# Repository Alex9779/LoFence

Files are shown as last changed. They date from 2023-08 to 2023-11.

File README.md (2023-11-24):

# LoFence V2

LoFence V2 is an updated version of the original [LoFence](https://github.com/kiu/lofence/) tackling a few shortcomings.

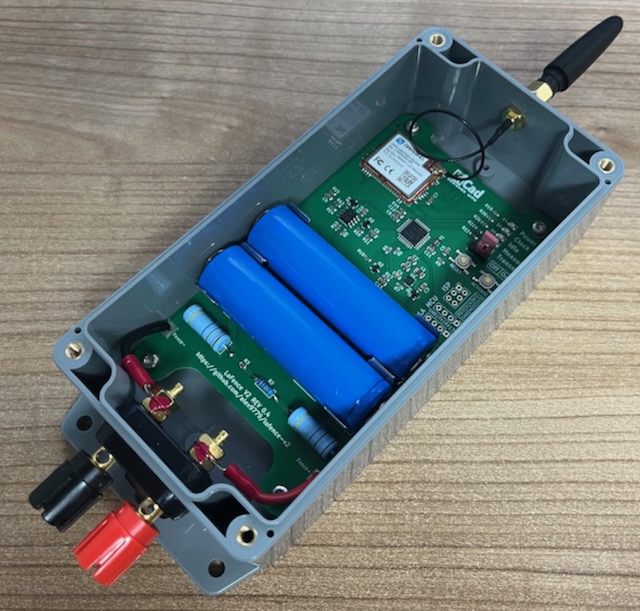
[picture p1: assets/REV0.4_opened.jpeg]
LoFence V2 opened


The main improvements are:

- case lid can be opened while main body is mounted,
- two batteries for a longer operating time,
- battery deep discharge protection using an activation circuit with a button triggered from the firmware when batteries run low,
- fully revised firmware with ability to change operating parameters by downlinks.

Other things changed are:

- Exchange RN2483 module for Dragino LA66.
  - I always had some problems with the RN2483 though serial communication protocol was easier to work with.
  - LA66 has antenna connector on board so I don't have to care about a correct antenna circuit which also has to follow the guidelines to not to violate regulatory approvals.
  - LA66 is a little cheaper.
- Implement probe resistor divider erratum.
- Optimized for assembling.
  - Changed various components to SMD variants.
  - Switch to buck-boost converter for power supply.
  - Use clamps for holding batteries instead of full holder.

For information how to build a LoFence V2 device see the [hardware repository](https://github.com/Alex9779/LoFence_Hardware).

For information how to build, upload or configure the firmware see the [firmware repository](https://github.com/Alex9779/LoFence_Firmware).

## WARNING

Do not let the debug LEDs activated during normal operation!

They need a lot of current compared to the overall device's current usage. So if activated they drastically reduce the battery runtime to just some weeks or even days.

## Device activation

The LoFence V2 is equipped with an activation circuit allowing the device to deactivate itself if the battery voltage goes under a configured level (3200mV by default for 5 cycles or 3100mV as an absolute minumum) to prevent the battery from deep discharge.

Therefore the device does not automatically activate if a battery is put in but you have to push and hold the *ACTIVATE* button for at least 1 second.

If the debug LEDs are activated the *IDLE* LED indicates that the activation process has been completed when it goes out.

After activation the device tries to join (re-join) the network, LoRaWAN counters are reset.

If joining succeeds the device will immediately do the first measurement and after that transmits the first uplink.

## Device resetting

To reset the device push the *RESET* button. After a reset the device has to be activated again.

A reset is just the same as removing all batteries and put them back in and activate the device.

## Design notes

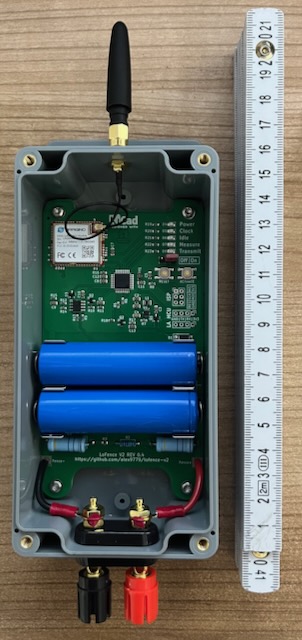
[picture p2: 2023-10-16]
assets/REV0.4_opened_with_rule.jpeg

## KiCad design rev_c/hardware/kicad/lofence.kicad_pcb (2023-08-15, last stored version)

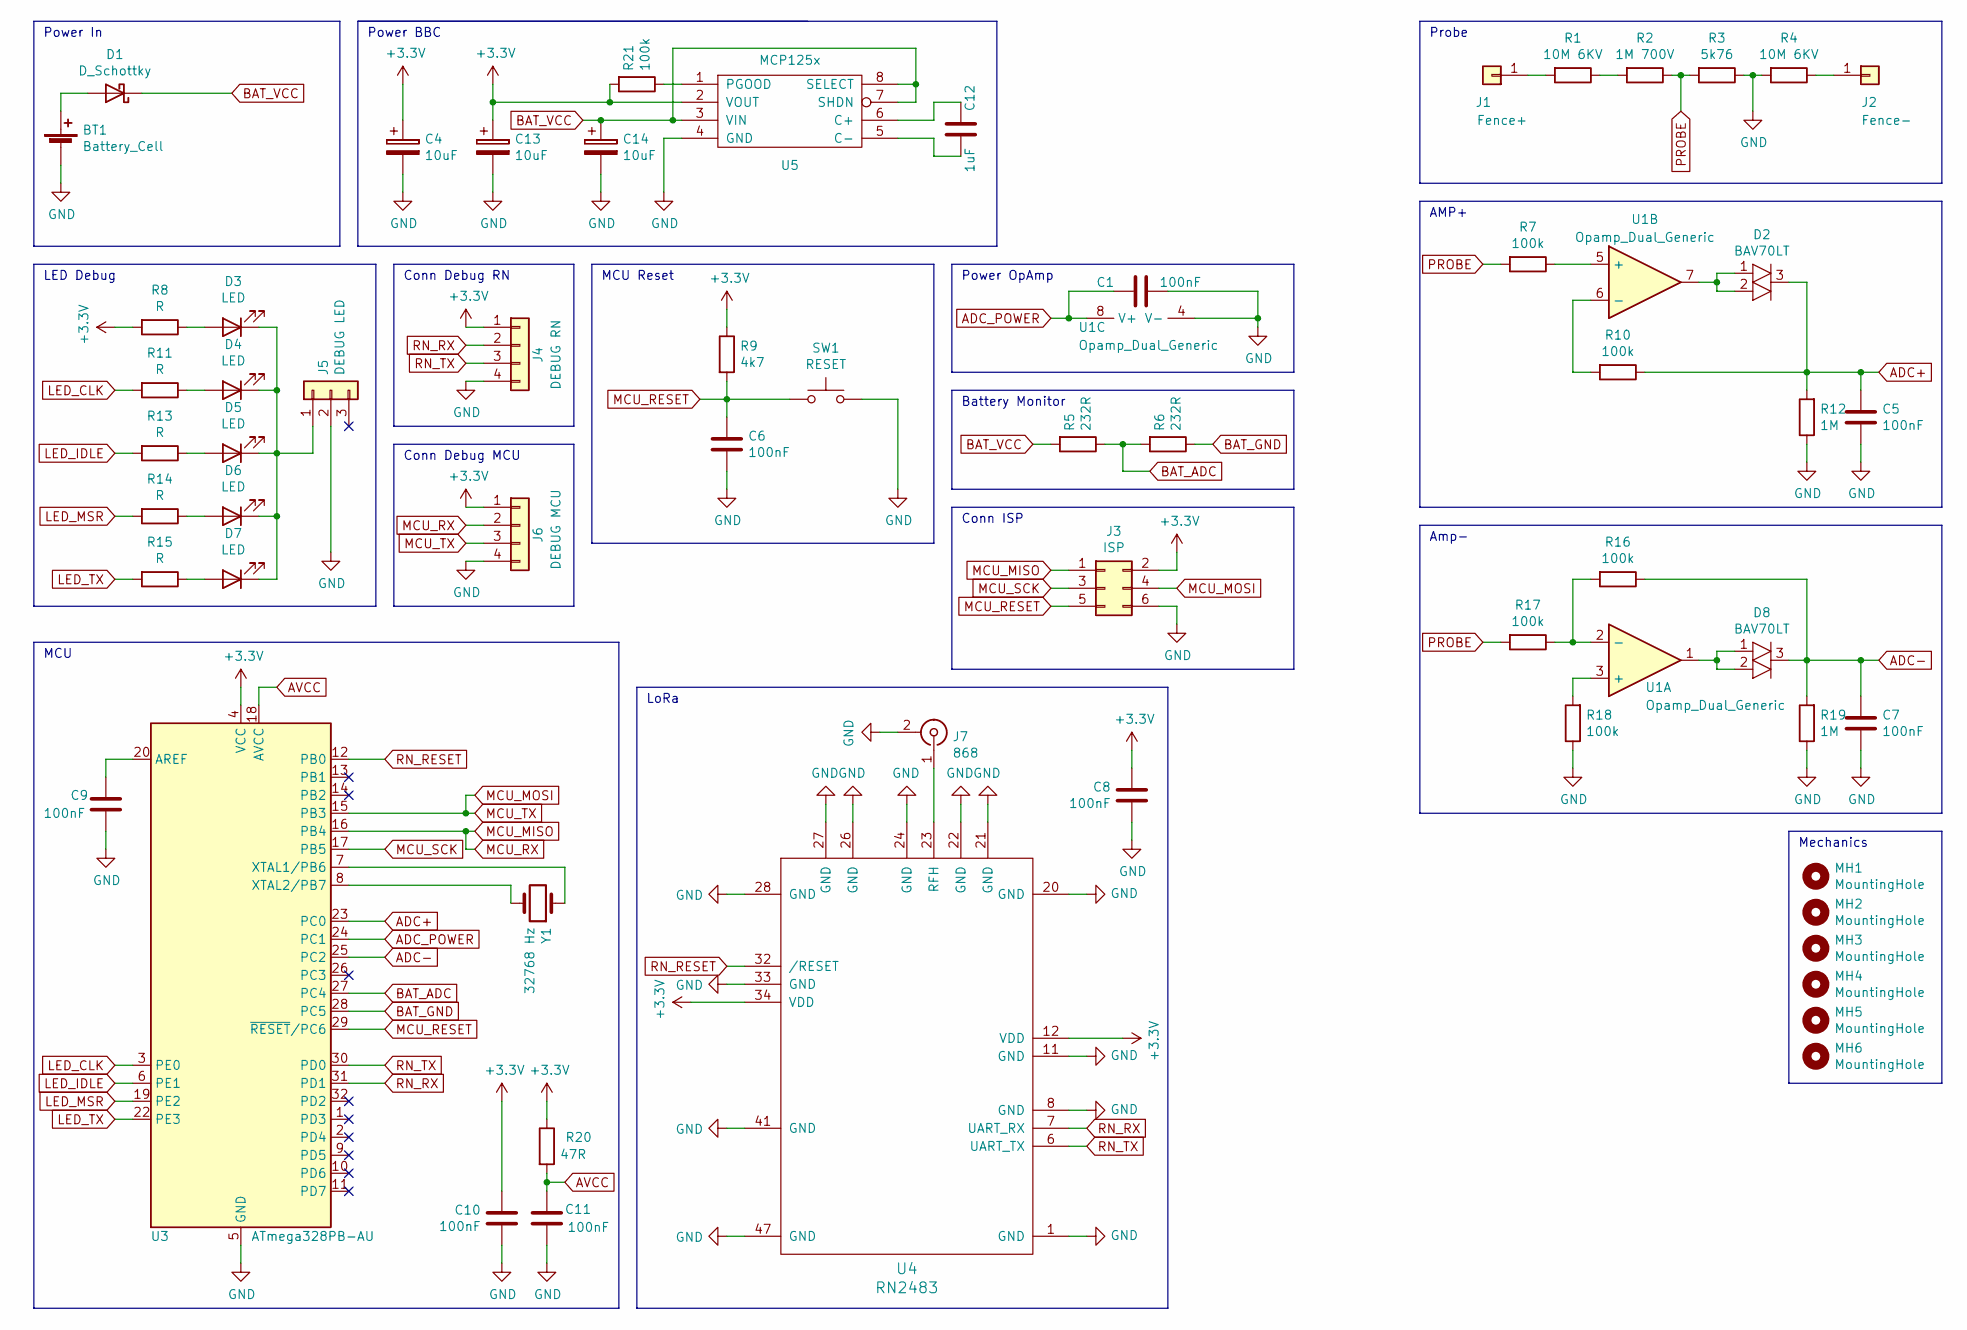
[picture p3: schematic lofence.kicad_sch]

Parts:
BT1: Battery_Cell; 18650HolderTHT
C1, C5, C6, C7, C8, C9, C10, C11: 100nF; C_0805_2012Metric_Pad1.18x1.45mm_HandSolder
C4: 10uF; CP_Elec_4x5.7
C12: 1uF; C_0805_2012Metric_Pad1.18x1.45mm_HandSolder
C13, C14: 10uF; C_1206_3216Metric_Pad1.33x1.80mm_HandSolder
D1: D_Schottky; D_SMA_Handsoldering
D2, D8: BAV70LT; SOT-23
D3, D4, D5, D6, D7: LED; LED_0805_2012Metric_Pad1.15x1.40mm_HandSolder
J1: Fence+; TestPoint_THTPad_4.0x4.0mm_Drill2.0mm
J2: Fence-; TestPoint_THTPad_4.0x4.0mm_Drill2.0mm
J3: ISP; PinHeader_2x03_P2.54mm_Vertical
J4: DEBUG RN; PinHeader_1x04_P2.54mm_Vertical
J5: DEBUG LED; PinHeader_1x03_P2.54mm_Vertical
J6: DEBUG MCU; PinHeader_1x04_P2.54mm_Vertical
J7: 868; U.FL
MH1, MH2, MH3, MH4, MH5, MH6: MountingHole; MountingHole_2.7mm_M2.5
R1, R4: 10M 6KV; R_Axial_DIN0516_L15.5mm_D5.0mm_P20.32mm_Horizontal
R2: 1M 700V; R_Axial_DIN0207_L6.3mm_D2.5mm_P10.16mm_Horizontal
R3: 5k76; R_0805_2012Metric_Pad1.20x1.40mm_HandSolder
R5, R6: 232R; R_0805_2012Metric_Pad1.20x1.40mm_HandSolder
R7, R10, R16, R17, R18, R21: 100k; R_0805_2012Metric_Pad1.20x1.40mm_HandSolder
R8, R11, R13, R14, R15: R; R_0805_2012Metric_Pad1.20x1.40mm_HandSolder
R9: 4k7; R_0805_2012Metric_Pad1.20x1.40mm_HandSolder
R12, R19: 1M; R_0805_2012Metric_Pad1.20x1.40mm_HandSolder
R20: 47R; R_0805_2012Metric_Pad1.20x1.40mm_HandSolder
SW1: RESET; SW_SPST_B3SL-1002P
U1: Opamp_Dual_Generic; SOIC-8_3.9x4.9mm_P1.27mm
U3: ATmega328PB-AU; TQFP-32_7x7mm_P0.8mm
U4: RN2483; RN2483_serial
U5: MCP125x; MSOP-8_3x3mm_P0.65mm
Y1: 32768 Hz; Crystal_Round_D3.0mm_Vertical

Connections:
+3V3: C4.1, C8.2, C10.2, C13.1, J3.2, J4.1, J6.1, R8.2, R9.1, R20.1, R21.2, U3.4 (VCC), U4.12 (VDD), U4.34 (VDD), U5.2 (VOUT)
ADC+: C5.1, D2.3 (K), R10.1, R12.2, U3.23 (PC0)
ADC-: C7.1, D8.3 (K), R16.1, R19.2, U3.25 (PC2)
ADC_POWER: C1.1, U1.8 (V+), U3.24 (PC1)
AVCC: C11.2, R20.2, U3.18 (AVCC)
BAT_ADC: R5.1, R6.2, U3.27 (PC4)
BAT_GND: R6.1, U3.28 (PC5)
BAT_VCC: C14.1, D1.1 (K), R5.2, U5.3 (VIN), U5.7 (SHDN), U5.8 (SELECT)
GND: BT1.2 (-), C1.2, C4.2, C5.2, C6.2, C7.2, C8.1, C9.2, C10.1, C11.1, C13.2, C14.2, J3.6, J4.4, J5.2, J6.4, J7.2 (Ext), R3.1, R4.2, R12.1, R18.1, R19.1, SW1.2, U1.4 (V-), U3.5 (GND), U3.21 (GND), U4.1 (GND), U4.8 (GND), U4.11 (GND), U4.20 (GND), U4.21 (GND), U4.22 (GND), U4.24 (GND), U4.26 (GND), U4.27 (GND), U4.28 (GND), U4.33 (GND), U4.41 (GND), U4.47 (GND), U5.4 (GND)
LED_CLK: R11.2, U3.3 (PE0)
LED_IDLE: R13.2, U3.6 (PE1)
LED_MSR: R14.2, U3.19 (PE2)
LED_TX: R15.2, U3.22 (PE3)
MCU_MISO: J3.1, J6.2, U3.16 (PB4)
MCU_MOSI: J3.4, J6.3, U3.15 (PB3)
MCU_RESET: C6.1, J3.5, R9.2, SW1.1, U3.29 (~RESET/PC6)
MCU_SCK: J3.3, U3.17 (PB5)
unnamed: BT1.1 (+), D1.2 (A)
unnamed: C9.1, U3.20 (AREF)
unnamed: C12.1, U5.6 (C+)
unnamed: C12.2, U5.5 (C-)
unnamed: D2.1 (A1), D2.2 (A2), U1.7
unnamed: D3.1 (K), D4.1 (K), D5.1 (K), D6.1 (K), D7.1 (K), J5.1
unnamed: D3.2 (A), R8.1
unnamed: D4.2 (A), R11.1
unnamed: D5.2 (A), R13.1
unnamed: D6.2 (A), R14.1
unnamed: D7.2 (A), R15.1
unnamed: D8.1 (A1), D8.2 (A2), U1.1
unnamed: J1.1, R1.2
unnamed: J2.1, R4.1
unnamed: J7.1 (In), U4.23 (RFH)
unnamed: R1.1, R2.2
unnamed: R7.1, U1.5 (+)
unnamed: R10.2, U1.6 (-)
unnamed: R16.2, R17.1, U1.2 (-)
unnamed: R18.2, U1.3 (+)
unnamed: R21.1, U5.1 (PGOOD)
unnamed: U3.7 (XTAL1/PB6), Y1.1
unnamed: U3.8 (XTAL2/PB7), Y1.2
PROBE: R2.1, R3.2, R7.2, R17.2
RN_RESET: U3.12 (PB0), U4.32 (/RESET)
RN_RX: J4.2, U3.31 (PD1), U4.7 (UART_RX)
RN_TX: J4.3, U3.30 (PD0), U4.6 (UART_TX)

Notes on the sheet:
Power BBC
Conn ISP
Battery Monitor
Conn Debug MCU
AMP+
MCU
Conn Debug RN
Mechanics
Power In
MCU Reset
Power OpAmp
LoRa
LED Debug
Probe
Amp-

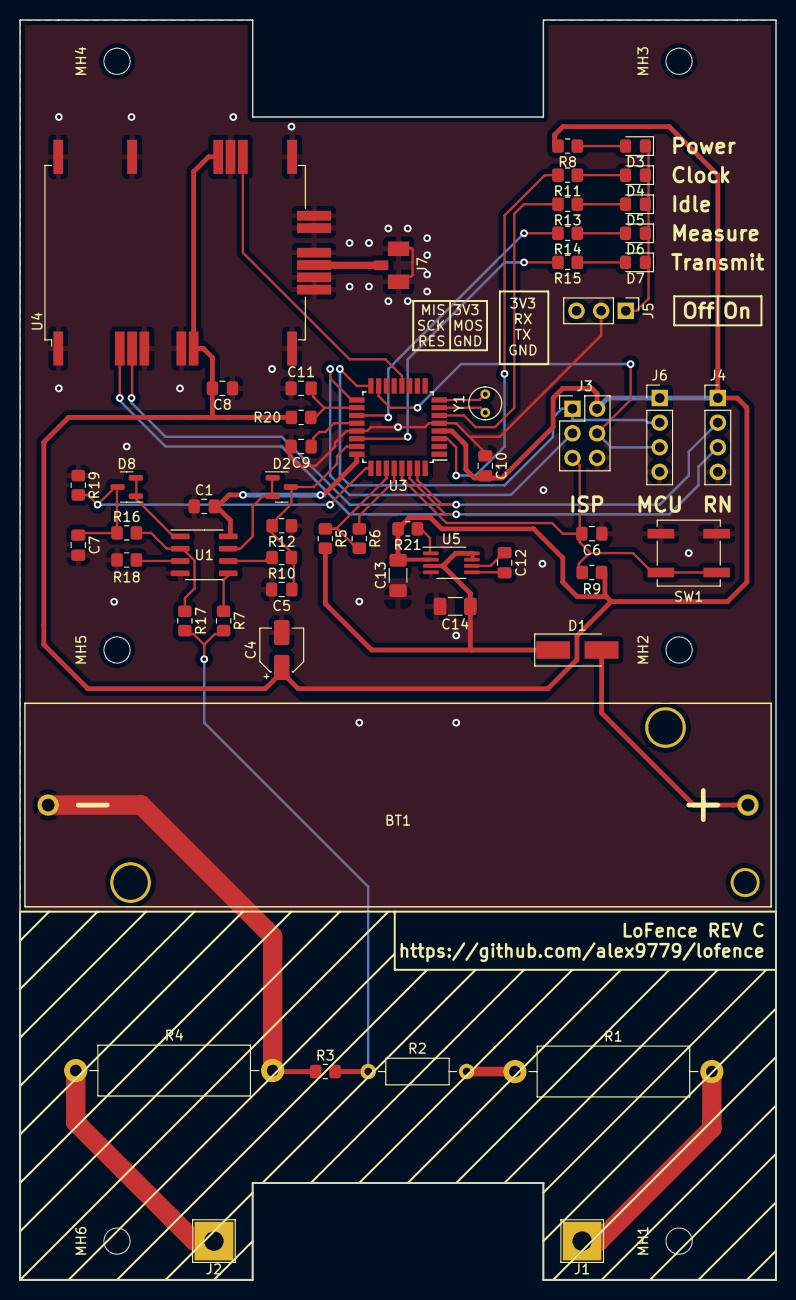
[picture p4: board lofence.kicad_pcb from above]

Board: 2 copper layers, 78.0 x 130.0 mm, 61 parts (0 on the bottom side), 44 nets.

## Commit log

2023-08-15 create rev c
    - adapt errata of rev b
    - update symbols and footprints
    - clean board
    [lofence.kicad_pcb, lofence.kicad_sch]
2023-08-15 additional cleaning
    [lofence.kicad_pcb]
2023-08-15 fix battery power
    [lofence.kicad_pcb, lofence.kicad_sch]
2023-10-14 initial commit for V2
    [bom.ods, calculations.ods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]
2023-10-19 add calculations
    [calculations.ods]
